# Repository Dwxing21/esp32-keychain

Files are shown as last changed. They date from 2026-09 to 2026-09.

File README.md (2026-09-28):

# ESP32-S3 smartwatch: clock + Spotify controls + Maps nav

Two parts:
- `firmware/` — PlatformIO project for the Waveshare ESP32-S3-LCD-1.28 (GC9A01 round display, no touch). Runs a BLE GATT server, draws three screens (clock, Spotify, navigation), and reads the BOOT button for playback control / screen cycling.
- `android-app/` — Android Studio project. Reads Spotify's now-playing info and Google Maps' navigation notifications, and relays both to the watch over BLE. Also receives playback commands (play/pause, next) from the watch's BOOT button and forwards them to Spotify.

## How data flows

```
Spotify app  ---MediaSession--->  \
                                    Android companion app  ---BLE--->  ESP32-S3 watch
Google Maps  ---notification--->  /                        <--BLE---  (playback commands)
```

The watch never talks to WiFi, Spotify's API, or Google's API directly — the phone does all of that and just pushes simple text/state over BLE. This also means the watch gets its clock from the phone (over BLE) rather than NTP, so no WiFi credentials are needed on the watch at all.

## Firmware setup (PlatformIO)

1. Install the [PlatformIO extension](https://platformio.org/install/ide?install=vscode) for VS Code (or use the PlatformIO CLI).
2. Open the `firmware/` folder as a PlatformIO project.
3. Connect the board over USB-C, then **Build & Upload**.
4. Open the serial monitor (115200 baud) — you should see `[BLE] GATT server up, advertising as 'ESP32 Smartwatch'`.

**If the display stays blank:** double-check the pins in `include/User_Setup.h` against your board's schematic (linked in that file) — Waveshare has shipped slightly different pinouts across batches.

**Screen behavior:**
- The cycle is now four screens: main/clock -> Spotify -> lyrics -> navigation -> back to main.
- Boots to the main/clock screen. If music is already playing or navigation is already active by the time the phone connects, it jumps there once automatically (lyrics is never auto-jumped to -- it's a secondary view you reach by cycling) -- after that (or after your first button press), it's fully manual.
- If the phone isn't connected, the Spotify and nav screens show a "Connect to phone" message with a battery icon instead of stale/empty content. The clock screen is exempt from this -- it keeps working on its own using the last-known or persisted time, since a watch that can't show the time without a nearby phone defeats the point. (If you actually want the clock replaced too, that's a one-line change -- just ask.)
- The clock shows the last-synced time immediately on boot instead of a blank screen, saved to flash via NVS (`time_store.cpp`) each time the phone syncs. There's no battery-backed RTC chip on this board, so this doesn't account for how long the device was powered off -- it's a best-effort "don't show nothing" measure, corrected within seconds once the phone reconnects. The phone also re-syncs every 30 minutes while connected (not just once), to catch clock drift or a DST change.
- Date is shown as day-month-year (e.g. `25-09-2026`).
- The battery icon reads from `battery.cpp`, which uses GPIO1 (this board's confirmed BAT_ADC pin) to estimate a percentage. The pin is confirmed, but the voltage-divider ratio (`DIVIDER_RATIO`, currently assumed 2.0) and the empty/full voltage thresholds haven't been verified against a multimeter reading of your actual battery -- worth checking once you're testing, since a wrong ratio means a wrong percentage even though the pin itself is right.

**BOOT button behavior:**
- Clock/nav screens: click or double-click cycles to the next screen.
- Spotify screen: click = play/pause, double-click = next track, long-press = leave the screen (there's no button gesture for "previous track" yet — wire a second button to a spare GPIO if you want one, and I can add the firmware/BLE/app-side handling for it).

## Android app setup

1. Open `android-app/` in Android Studio, let it sync Gradle.
2. Run it on a phone (not an emulator — you need real Bluetooth and the Spotify/Maps apps installed).
3. In the app: tap **Grant notification access**, and enable "Smartwatch notification reader" in the system settings page that opens. This is what lets it read Spotify's media session and Google Maps' notifications — there's no runtime permission dialog for this, Android requires the manual settings toggle.
4. Tap **Connect to watch** and accept the Bluetooth permission prompts.
5. Play something in Spotify — the watch's Spotify screen should update. Start turn-by-turn navigation in Google Maps — the watch's nav screen should update.

**Keeping it connected:** Android will eventually kill the notification listener / BLE connection in the background on many phones unless you disable battery optimization for this app (Settings → Apps → Smartwatch Companion → Battery → Unrestricted). A proper foreground service with a persistent notification would help here too — this skeleton doesn't include one yet.

## Known limitations / things worth knowing before you build on this

- **Google Maps nav parsing is best-effort.** It reads whatever text Maps puts in its persistent navigation notification's title/text fields. Google can change that layout without notice, which would break the parsing — there's no official API for this.
- **Distance units follow Google Maps' own setting, not ours.** The nav distance shown on the watch (e.g. "90 m" vs "300 ft") is relayed verbatim from Maps' notification text — our code never sees a raw number, just a string, so it can't convert units itself. To get metric on the watch, set it in Google Maps' own app settings (Settings → Navigation settings → Distance units), or your phone's region.
- **No "previous track" button gesture** — see the BOOT button section above.
- **No reconnection UI feedback** beyond logcat — the app will keep retrying the BLE scan every 3 seconds if disconnected, but the status text on screen doesn't reflect that yet.
- iOS is not supported for the Spotify-reading half of this (Apple doesn't expose background media session data the way Android does) — this whole approach is Android-only.

## Lyrics

A dedicated screen in the cycle shows the current lyric line, synced to playback position. A few things worth knowing:

- **Spotify has no public lyrics API**, so this doesn't come from Spotify at all. It uses [lrclib.net](https://lrclib.net) -- a free, community-run lyrics database with synced (per-line timestamped) lyrics, no API key needed. `LyricsFetcher.kt` handles the lookup and LRC parsing.
- On a track change, the phone app clears the old lyrics immediately, fetches new ones in the background (network call, so there's a brief "no lyrics" flash even for tracks that do have them), and starts polling playback position every 500ms to catch line changes.
- **Coverage is inconsistent** -- mainstream tracks are usually covered, obscure or very new releases often aren't. When nothing's found, the screen just says "No lyrics found" rather than erroring.
- This is the first thing in the project that needs phone internet access, so `INTERNET` permission was added to the manifest. It only talks to lrclib.net -- no account, no auth, no data sent beyond track/artist/duration for the lookup.
- The word-wrap on the watch (`drawWrappedText` in `display.cpp`) shows up to 3 lines before truncating -- fine for a single lyric line, but a good thing to know if a source ever returns unusually long lines.

## UI icons and screen previews

`firmware/src/icons.h` has 19 generated icon bitmaps (play/pause/prev/next, four nav arrows, 5-level battery in two sizes, a disconnected-Bluetooth glyph) wired into `display.cpp` via `tft.drawXBitmap()`, replacing the earlier placeholder circles/text. `firmware/previews/` has renders of all six screen states (clock, disconnected, Spotify playing/paused, nav straight/left) at actual layout -- generated by simulating the exact draw calls and coordinates from `display.cpp`, masked to the round display, so they reflect real positioning, not just mockups. Worth knowing:
- The preview font is a stand-in (DejaVuSansMono) for TFT_eSPI's built-in GLCD font -- close in spirit, not pixel-identical, so expect minor differences on real hardware.
- Rendering these caught a real bug: a long track title or nav instruction would have run off the screen entirely. `display.cpp` now has a `truncateToFit()` helper that measures text width and adds "..." before it overflows -- applied to track name, artist, and nav instruction.
- If you design your own versions in Lopaka later, match these exact pixel sizes so they drop into the existing layout: play/pause 32x32, prev/next 28x28, nav arrows 40x40, battery 26x13 (small) and 50x24 (large), Bluetooth glyph 24x24.

## Power source

Your exact board (the plain, non-touch ESP32-S3-LCD-1.28) has a real onboard charging circuit — an **ETA6096 Li-ion charge manager** — and an **MX1.25 2-pin battery connector**. That means you can plug a 3.7V single-cell LiPo straight into that header, and USB-C both powers the board and charges the battery at the same time. No extra charging module needed.

What to get:
- A **3.7V single-cell LiPo with an MX1.25 (JST 1.25mm pitch) 2-pin connector**, correct polarity (check the board's silkscreen "+"/"-" against the wire colors before plugging in — reversed polarity on a LiPo is a real fire risk).
- Capacity: 100–200mAh is a sensible range for something this small. `case/keychain_case.scad` has a battery pocket sized for a ~25×20×5mm cell (roughly a 302025 or similar); a 502030-size cell would need the pocket resized larger.
- Watch battery life expectations: with the display on and BLE connected continuously, runtime will likely be a few hours, not days, on a 100–150mAh cell. Adding a sleep/dim mode (mentioned as a "still to do" in the firmware notes) would meaningfully extend that.

Don't use a LiPo without a protection circuit built in (most pre-wired ones sold for hobby electronics have one) — the ETA6096 handles charge control, but cell-level over-discharge/short protection should still be present on the battery itself.

## 3D-printed keychain case

`case/keychain_case.scad` is a parametric OpenSCAD design: a two-part shell (body + lid) that holds the board, has a battery pocket, cutouts for the USB-C port and BOOT button, and a keychain loop. Rendered STLs (`case/keychain_case_body.stl`, `case/keychain_case_lid.stl`) and preview renders (`case/preview_body.png`, `case/preview_lid.png`) are included so you can see the design without opening OpenSCAD.

**Read the comment block at the top of the .scad file before printing.** The display opening (32.4mm) is solid — that's just what "1.28 inch round" means — but the PCB's outer diameter and exactly where the USB-C port / BOOT button / battery connector sit around the edge are estimates, since Waveshare only publishes a PDF drawing, not machine-readable dimensions. Measure your actual board and adjust the variables at the top of the file (all clearly marked) before committing filament to a full-quality print. A quick low-infill draft print of just the body is a cheap way to test the fit first.

To tweak and re-render: install [OpenSCAD](https://openscad.org/downloads.html), open `keychain_case.scad`, change `part = "body"` to `"lid"` or `"both"`, adjust the marked variables, and render (F6) then export as STL (F7).

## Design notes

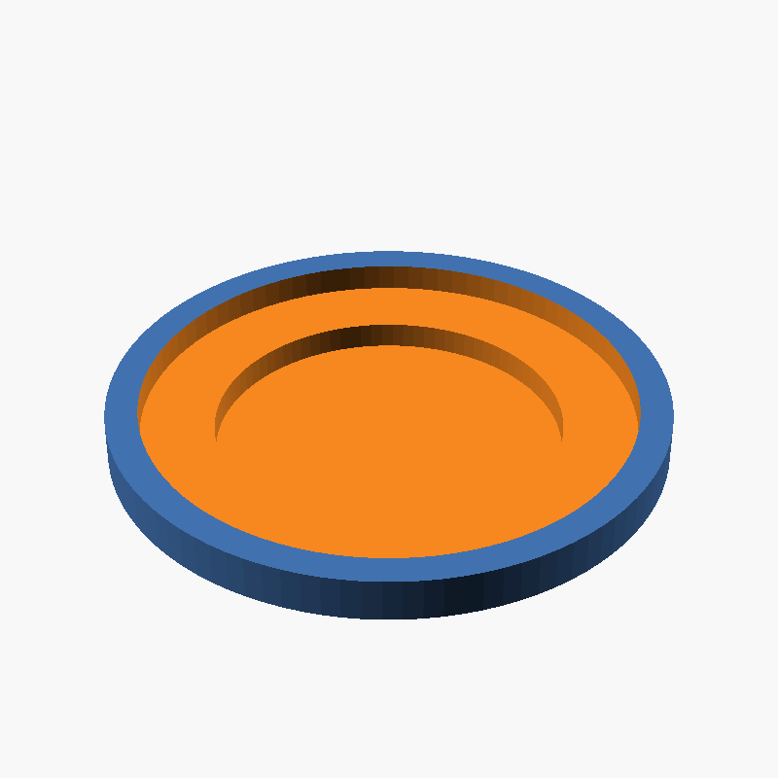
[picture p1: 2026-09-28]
case/preview_lid.png

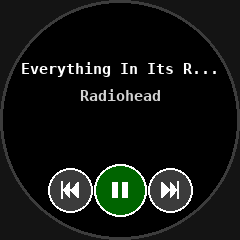
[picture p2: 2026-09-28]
firmware/previews/screen_spotify_playing.png

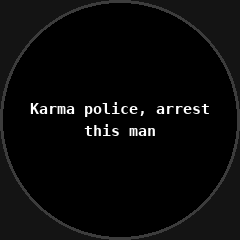
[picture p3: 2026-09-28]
firmware/previews/screen_lyrics.png

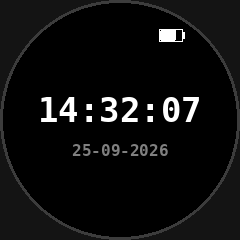
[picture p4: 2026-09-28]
firmware/previews/screen_clock.png

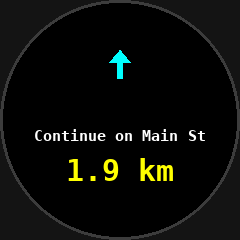
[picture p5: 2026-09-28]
firmware/previews/screen_nav_straight.png

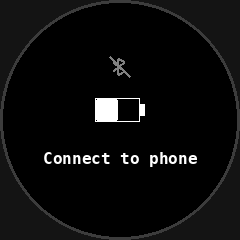
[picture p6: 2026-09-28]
firmware/previews/screen_disconnected.png

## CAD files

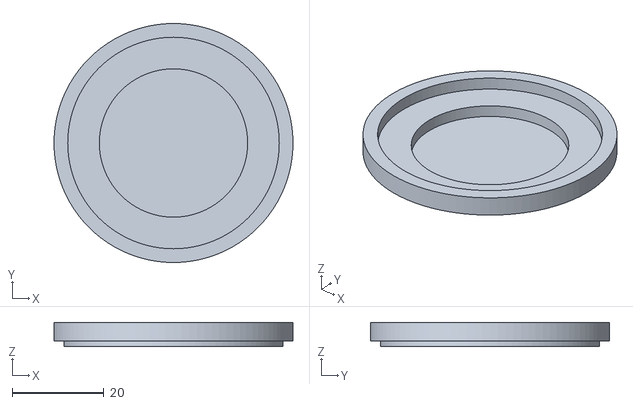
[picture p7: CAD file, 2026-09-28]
case/keychain_case_lid.stl
52.2 x 52.2 x 5.30

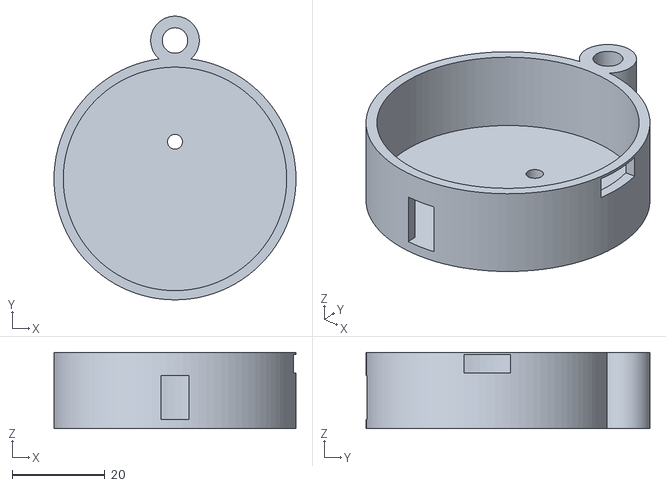
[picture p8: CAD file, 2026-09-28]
case/keychain_case_body.stl
52.2 x 61.2 x 16.5

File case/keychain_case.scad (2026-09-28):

// ============================================================================
// Keychain case for the Waveshare ESP32-S3-LCD-1.28 (round GC9A01, no touch)
// ============================================================================
//
// IMPORTANT -- read before printing:
// The display opening (32.4mm) is a solid number: a "1.28 inch" round panel
// is 32.51mm across by definition, so that part is trustworthy.
// The PCB outer diameter, and WHERE the USB-C port / BOOT button / battery
// connector sit, are NOT things I have a verified drawing for -- Waveshare
// only publishes those as a PDF image, not machine-readable numbers. Also
// note: the BOOT button is mounted on the board's BACK face (confirmed), not
// its edge, so its access hole goes through the case's back floor, not the
// side wall like the USB-C port does. Before printing:
//   1. Measure your actual board's diameter with calipers and update
//      board_diameter below.
//   2. With the board back-side up and USB-C pointing toward you (6 o'clock),
//      measure the BOOT button's position from board center and update
//      boot_x/boot_y. Note the USB-C port's edge position too and update
//      usb_c_angle if needed.
//   3. Print the BODY alone first in draft quality (thick layers, low infill)
//      as a fit test before committing filament to a nicer finish.
//
// Prints as two parts -- set part below, or "both" just to look at them
// together (don't print "both" as one plate).

part = "body";  // "body" | "lid" | "both"

// ---- Board dimensions (VERIFY board_diameter against your real board) ----
board_diameter   = 37.6;  // outer edge of the round PCB, mm -- ESTIMATE, VERIFY
display_active_d = 32.4;  // "1.28 inch" round glass = 32.51mm -- this one's solid
board_thickness  = 1.6;   // standard PCB thickness
component_clearance = 5;  // depth below the board for USB-C jack / battery connector / any header pins

// ---- USB-C cutout on the case wall (VERIFY POSITION) ----
usb_c_width  = 10;
usb_c_height = 4;
usb_c_angle  = 270;   // degrees around the case where the port sits (270 = "6 o'clock")

// ---- BOOT button access hole (VERIFY POSITION) ----
// This board's BOOT button is mounted on the board's BACK face, not its edge --
// so this drills a vertical hole through the case's back FLOOR, not the side
// wall. To find boot_x/boot_y: look at the back of your board with the USB-C
// port pointing toward you (6 o'clock), then measure the button's center from
// the board's middle, left/right and up/down, in mm. The values below are a
// placeholder guess, not a measurement.
boot_hole_d = 3.2;
boot_x = 0;   // mm from board center, left(-) / right(+) -- ESTIMATE, VERIFY
boot_y = 8;   // mm from board center, away-from-USB-C(+) / toward-it(-) -- ESTIMATE, VERIFY

// ---- Battery connector wire slot, from the pocket up to the board ----
batt_conn_angle = 180; // 180 = "9 o'clock" -- opposite the USB-C port by default

// ---- Battery compartment (behind the board) ----
// Sized for the Grobotronics 3.7V 620mAh Molex-1.25mm cell (40x20x8.5mm),
// plus a little clearance for an easy fit and wire routing.
batt_length = 42;
batt_width  = 22;
batt_thickness = 9.5;

// ---- Case shell ----
wall = 2.0;
lid_lip = 1.2;         // how far the lid's inner lip plugs into the body
fit_clearance = 0.4;   // extra radius so the board isn't press-fit
keychain_loop_d = 5.5; // inner hole diameter for a keyring
keychain_loop_wall = 2.5;

$fn = 96;

// This battery's footprint (40x20mm) is close to the board's own diameter, so a
// case sized only to the board can't also enclose it -- the case grows to fit
// whichever is larger. With the 620mAh cell above, the battery is what drives
// the size: expect a ~52mm case, not a ~42mm one.
board_based_diameter = board_diameter + 2*fit_clearance + 2*wall;
battery_based_diameter = sqrt(pow(batt_length, 2) + pow(batt_width, 2)) + 2*wall + 2*fit_clearance;
case_diameter = max(board_based_diameter, battery_based_diameter);
body_depth = component_clearance + batt_thickness + wall;
lid_depth = board_thickness + 2.5;

// ---------------------------------------------------------------------------

module keychain_loop(h) {
    r_outer = keychain_loop_d/2 + keychain_loop_wall;
    translate([0, case_diameter/2 + r_outer - 1.5, h/2])
        difference() {
            cylinder(h = h, r = r_outer, center = true);
            cylinder(h = h + 2, r = keychain_loop_d/2, center = true);
        }
}

module body() {
    difference() {
        union() {
            cylinder(h = body_depth, d = case_diameter);
            keychain_loop(body_depth);
        }
        // hollow interior -- the battery just sits loose in here (secure it with a
        // strip of foam or double-sided tape), no separate pocket cut needed now
        // that it's roughly the same footprint as the board itself
        translate([0, 0, wall])
            cylinder(h = body_depth, d = case_diameter - 2*wall);

        // USB-C cutout through the wall
        rotate([0, 0, usb_c_angle])
            translate([0, case_diameter/2 - wall/2, body_depth - component_clearance/2])
                cube([usb_c_width, wall*3, usb_c_height], center = true);

        // BOOT button access hole through the BACK FLOOR (vertical) -- this
        // board's button is back-mounted, not edge-mounted, unlike the USB-C
        // port above which genuinely is on the edge
        translate([boot_x, boot_y, -1])
            cylinder(h = wall + 2, d = boot_hole_d);

        // slot for the battery connector wire to reach the board
        // (this one's still assumed edge-mounted -- worth double-checking
        // the same way you caught the button, since I haven't verified it either)
        rotate([0, 0, batt_conn_angle])
            translate([0, case_diameter/2 - wall/2, wall + batt_thickness/2])
                cube([6, wall*3, batt_thickness], center = true);
    }
}

module lid() {
    difference() {
        union() {
            cylinder(h = lid_depth, d = case_diameter);
            // inner lip that plugs into the body for a friction-fit close
            translate([0, 0, -lid_lip])
                cylinder(h = lid_lip, d = case_diameter - 2*wall - 0.4);
        }
        // display window
        translate([0, 0, -1])
            cylinder(h = lid_depth + 2, d = display_active_d);
        // thin the lip so it isn't one solid slab on top of the display
        translate([0, 0, 1.5])
            cylinder(h = lid_depth, d = case_diameter - 2*wall - 2);
    }
}

if (part == "body") body();
if (part == "lid") lid();
if (part == "both") {
    body();
    translate([case_diameter + 12, 0, 0]) lid();
}

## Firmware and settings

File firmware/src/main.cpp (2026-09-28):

#include <Arduino.h>
#include "display.h"
#include "input.h"
#include "ble_service.h"
#include "battery.h"
#include "time_store.h"

void setup() {
  Serial.begin(115200);
  delay(200);
  Serial.println("\nESP32-S3 smartwatch booting...");

  loadPersistedTime();  // show the last-known time immediately, before BLE reconnects
  initDisplay();
  initInput();
  initBattery();
  initBLE();
}

void loop() {
  updateInput();
  updateBattery();
  updateDisplay();
  delay(10);
}

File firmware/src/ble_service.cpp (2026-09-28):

#include "ble_service.h"
#include "shared_state.h"
#include "display.h"
#include "time_store.h"
#include <NimBLEDevice.h>

// ---- Service / characteristic UUIDs ----
// These must match BleUuids in the Android app's BleGattClient.kt exactly.
#define NOWPLAYING_SERVICE_UUID   "c9a01000-1000-4bd9-ba21-70e224d9b8a0"
#define CHAR_TRACK_INFO_UUID      "c9a01001-1000-4bd9-ba21-70e224d9b8a0"
#define CHAR_PLAYBACK_STATE_UUID  "c9a01004-1000-4bd9-ba21-70e224d9b8a0"
#define CHAR_PLAYBACK_CMD_UUID    "c9a01005-1000-4bd9-ba21-70e224d9b8a0"  // watch -> phone, NOTIFY
#define CHAR_LYRICS_LINE_UUID     "c9a01006-1000-4bd9-ba21-70e224d9b8a0"

#define NAV_SERVICE_UUID          "c9a02000-1000-4bd9-ba21-70e224d9b8a0"
#define CHAR_NAV_INSTRUCTION_UUID "c9a02001-1000-4bd9-ba21-70e224d9b8a0"
#define CHAR_NAV_ACTIVE_UUID      "c9a02002-1000-4bd9-ba21-70e224d9b8a0"

#define TIME_SERVICE_UUID         "c9a03000-1000-4bd9-ba21-70e224d9b8a0"
#define CHAR_SET_TIME_UUID        "c9a03001-1000-4bd9-ba21-70e224d9b8a0"

// Global state definitions (declared extern in shared_state.h)
NowPlayingState nowPlaying;
NavState navInfo;
LyricsState lyricsState;
volatile uint32_t baseEpoch = 0;
volatile uint32_t baseMillis = 0;
volatile int16_t utcOffsetMinutes = 0;
volatile bool phoneConnected = false;

class ServerCallbacks : public NimBLEServerCallbacks {
  void onConnect(NimBLEServer* server) override {
    Serial.println("[BLE] Phone connected");
    phoneConnected = true;
    notifyPhoneConnected();  // re-arms boot-style auto-follow, forces a redraw
  }
  void onDisconnect(NimBLEServer* server) override {
    Serial.println("[BLE] Phone disconnected, restarting advertising");
    phoneConnected = false;
    notifyPhoneDisconnected();  // forces an immediate redraw to the "no phone" state
    NimBLEDevice::startAdvertising();
  }
};

// Payload format: "<track>\n<artist>\n<0 or 1>"
class TrackInfoCallbacks : public NimBLECharacteristicCallbacks {
  void onWrite(NimBLECharacteristic* c) override {
    std::string v = c->getValue();
    size_t firstNl = v.find('\n');
    size_t secondNl = v.find('\n', firstNl + 1);
    if (firstNl == std::string::npos || secondNl == std::string::npos) return;
    nowPlaying.track = String(v.substr(0, firstNl).c_str());
    nowPlaying.artist = String(v.substr(firstNl + 1, secondNl - firstNl - 1).c_str());
    nowPlaying.isPlaying = v.substr(secondNl + 1) == "1";
    nowPlaying.dirty = true;
  }
};

class PlaybackStateCallbacks : public NimBLECharacteristicCallbacks {
  void onWrite(NimBLECharacteristic* c) override {
    std::string v = c->getValue();
    if (v.empty()) return;
    nowPlaying.isPlaying = (v[0] == 1);
    nowPlaying.dirty = true;
  }
};

// Payload format: "<instruction>\n<distance>\n<maneuverCode>"
class NavInstructionCallbacks : public NimBLECharacteristicCallbacks {
  void onWrite(NimBLECharacteristic* c) override {
    std::string v = c->getValue();
    size_t firstNl = v.find('\n');
    size_t secondNl = v.find('\n', firstNl + 1);
    if (firstNl == std::string::npos || secondNl == std::string::npos) return;
    navInfo.instruction = String(v.substr(0, firstNl).c_str());
    navInfo.distance = String(v.substr(firstNl + 1, secondNl - firstNl - 1).c_str());
    navInfo.maneuver = (uint8_t)atoi(v.substr(secondNl + 1).c_str());
    navInfo.active = true;
    navInfo.dirty = true;
  }
};

class NavActiveCallbacks : public NimBLECharacteristicCallbacks {
  void onWrite(NimBLECharacteristic* c) override {
    std::string v = c->getValue();
    if (v.empty()) return;
    navInfo.active = (v[0] == 1);
    navInfo.dirty = true;
  }
};

// Plain text: the current lyric line, sent whenever it changes. Empty string
// means "no lyrics" (either none found for this track, or nothing loaded yet).
class LyricsLineCallbacks : public NimBLECharacteristicCallbacks {
  void onWrite(NimBLECharacteristic* c) override {
    std::string v = c->getValue();
    lyricsState.currentLine = String(v.c_str());
    lyricsState.dirty = true;
  }
};

// 6 bytes little-endian: uint32 epoch seconds + int16 UTC offset in minutes
class SetTimeCallbacks : public NimBLECharacteristicCallbacks {
  void onWrite(NimBLECharacteristic* c) override {
    std::string v = c->getValue();
    if (v.size() < 6) return;
    uint32_t epoch;
    int16_t offset;
    memcpy(&epoch, v.data(), 4);
    memcpy(&offset, v.data() + 4, 2);
    baseEpoch = epoch;
    baseMillis = millis();
    utcOffsetMinutes = offset;
    persistTime();  // save it so a reboot starts from here instead of blank
    Serial.printf("[BLE] Time synced: epoch=%u offset=%d min\n", epoch, offset);
  }
};

static NimBLECharacteristic* g_playbackCmdChar = nullptr;

void notifyPlaybackCommand(PlaybackCommand cmd) {
  if (g_playbackCmdChar == nullptr) return;
  uint8_t value = (uint8_t)cmd;
  g_playbackCmdChar->setValue(&value, 1);
  g_playbackCmdChar->notify();
}
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

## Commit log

2026-09-28 Add PlatformIO configuration for ESP32-S3 board
2026-09-28 Add User_Setup.h for ESP32-S3-LCD-1.28
    Added user setup configuration for ESP32-S3-LCD-1.28 display.
2026-10-17 Prepare smartwatch project for GitHub
    Refresh the README, publish the Android app and firmware sources, and remove the existing case files so they can be replaced.
